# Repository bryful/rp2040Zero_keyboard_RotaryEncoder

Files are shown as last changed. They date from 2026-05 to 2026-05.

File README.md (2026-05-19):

# RP2040 Zero Macro Keyboard + Dual Rotary Encoder

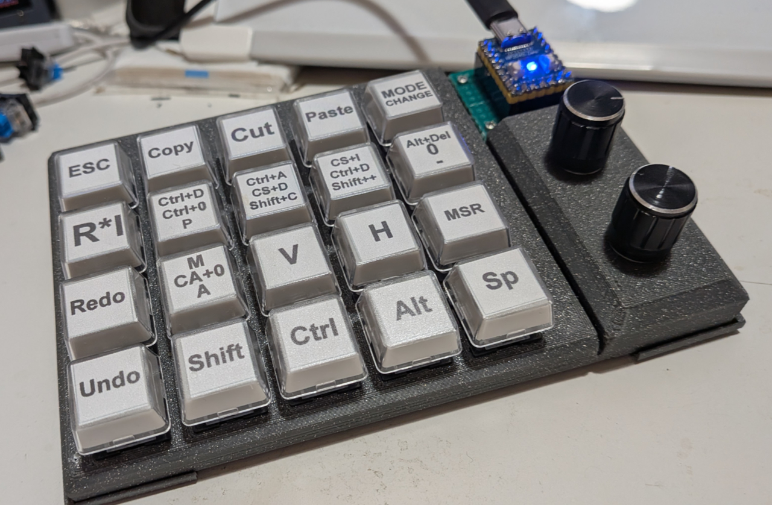
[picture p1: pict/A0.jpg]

Waveshare RP2040 Zero 用の USB HID マクロキーボードです。
4x5 キーマトリクスと 2 基のロータリーエンコーダを入力として使い、
Photoshop / After Effects / Illustrator の 3 モードでショートカットを送信します。
<br>
3dpフォルダの中に3Dプリンター用のデータも入れてあります。

## 特徴

- 4x5 キーマトリクス（20 キー）
- ロータリーエンコーダ x2（回転 CW/CCW + 押し込み SW）
- 3 つのアプリ向けキーマップモード
- モード切替キー（%1）
- USB HID キーボード + マウス右クリック送信
- WS2812 (NeoPixel) 1 灯で状態表示
- 一定時間無操作時のマウスジグル
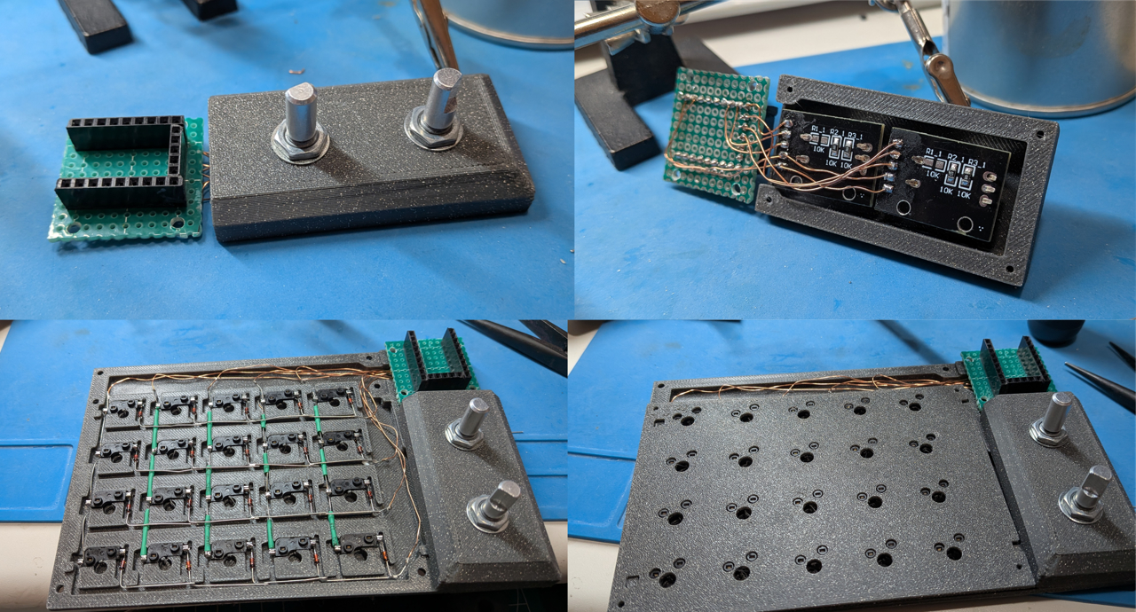
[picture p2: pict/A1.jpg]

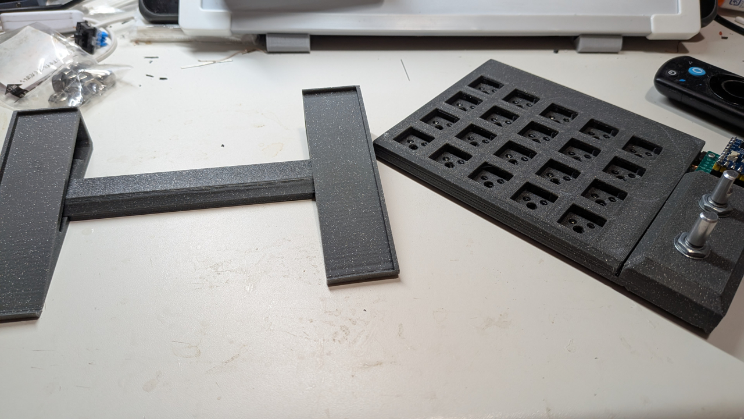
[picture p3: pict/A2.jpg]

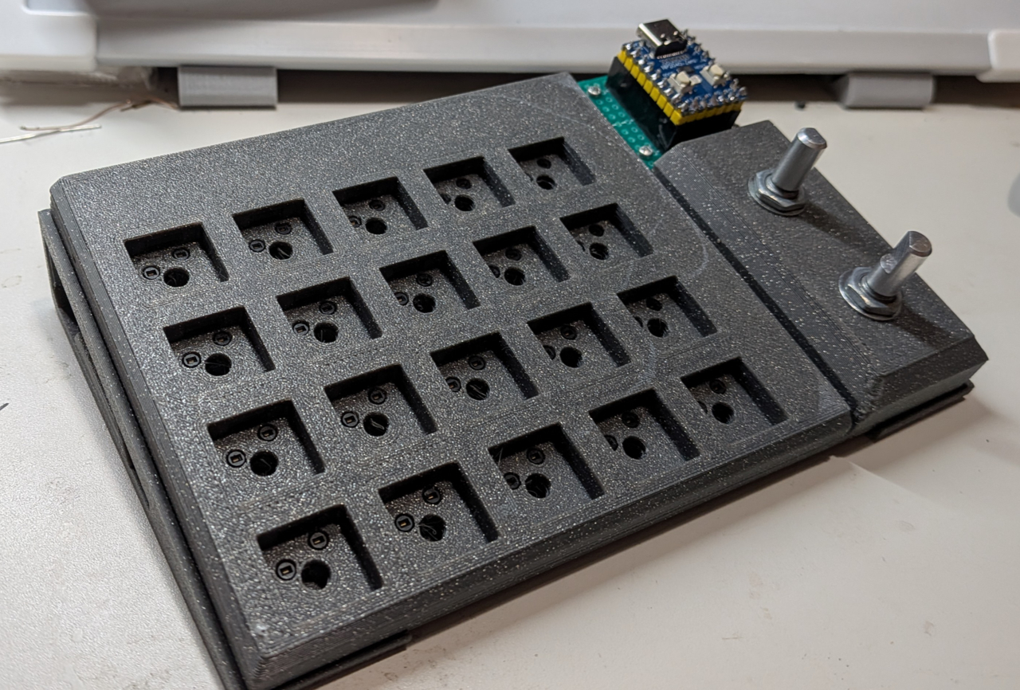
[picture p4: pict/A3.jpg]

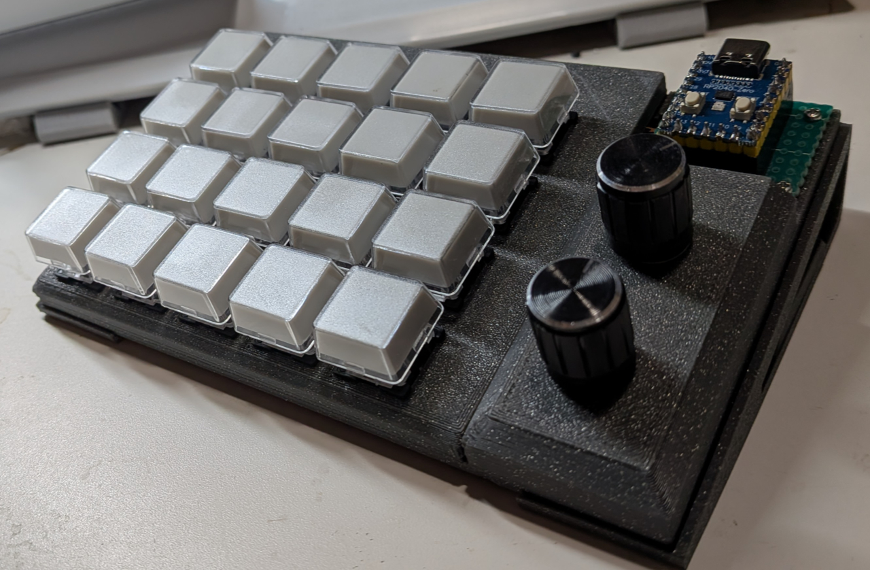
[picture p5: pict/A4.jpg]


## 日本語キーボード
ardiunoの基本だと英語キーボードになってます。そのままだと使えないので ** USBHIDKeyboard_JIS.h ** を作成し無理やり対応させています。

## ハードウェア

| 項目 | 内容 |
| --- | --- |
| マイコン | Waveshare RP2040 Zero |
| フレームワーク | Arduino (PlatformIO) |
| USB | TinyUSB ベース HID（Keyboard/Mouse） |
| LED | WS2812 x1（GPIO16） |
| キー入力 | 4x5 マトリクス（Rows: GPIO5,4,3,2 / Cols: GPIO6,7,8,9,10） |
| ロータリーエンコーダ | 2 基（A/B/SW それぞれ GPIO 割当あり） |

キー入力は INPUT_PULLUP 想定です（スイッチ押下で GND に落とす配線）。

## ピンアサイン

### キーマトリクス

| 種別 | GPIO |
| ---- | --- |
| Row  | 5, 4, 3, 2 |
| Col  | 6, 7, 8, 9, 10 |

### ロータリーエンコーダ

| エンコーダ | CLK(A) | DT(B) | SW  |
| --- | --- | ----- | --- |
| Encoder 1  | 11 | 12 | 13  |
| Encoder 2  | 14 | 15 | 26  |

### LED

| デバイス | GPIO |
| --- | ---- |
| WS2812 | 16 |

## モードとキーマップ

モードは 3 つです。

1. Photoshop
2. After Effects
3. Illustrator

モード切替キー（%1）を押すと順番に切り替わります。

### 共通キー（全モード共通）

キー割り当てはアプリを作って作成しました。
[https://github.com/bryful/rp2040Zero_Keybord](https://github.com/bryful/rp2040Zero_Keybord)

- ESC
- Ctrl+C
- Ctrl+X
- Ctrl+V
- Ctrl+Shift+Z（Redo）
- Ctrl+Z（Undo）
- Shift / Ctrl / Alt / Space
- Mouse Right Click

### ロータリーエンコーダ割り当て

#### Photoshop

- Enc0: CW = Ctrl+Keypad+, CCW = Ctrl+Keypad-, Push = Ctrl+0
- Enc1: CW = [, CCW = ], Push = B

#### After Effects

- Enc0: CW = -, CCW = ^, Push = なし
- Enc1: CW = ,, CCW = ., Push = なし

#### Illustrator

- Enc0: CW = Ctrl+Keypad+, CCW = Ctrl+Keypad-, Push = Ctrl+0
- Enc1: CW = Shift+H, CCW = V, Push = Ctrl+Shift+1

## LED 動作

- 起動時: 赤
- 起動完了時: 緑を点滅後にモード色へ遷移
- モード表示
  - Photoshop: 消灯
  - After Effects: 暗い青
  - Illustrator: 暗い黄

## スクリーンセーバー対策

一定時間入力がない場合、マウスポインタを小さく往復移動させるマウスジグルを実行します。

デフォルトは 3 分です。

```cpp
constexpr uint32_t SCREENSAVER_TIMEOUT_MS = 60000 * 3;
```

## ビルドと書き込み

### 必要環境

- VS Code
- PlatformIO 拡張
- RP2040 Zero（BOOTSEL モードで書き込み）

### PlatformIO 設定

- board: waveshare_rp2040_zero
- platform: raspberrypi
- framework: arduino
- upload_protocol: picotool
- lib_deps: Adafruit NeoPixel

### コマンド

```sh
pio run
pio run -t upload
pio device monitor -b 115200
```

## ディレクトリ構成

```text
.
|- platformio.ini
|- src/
|  |- main.cpp
|  |- USBHIDKeyboard_JIS.h
|- include/
|- lib/
|- test/
`- icons/
```

## 注意事項

- マトリクス配線はチャタリングやゴースト対策のため、必要に応じてダイオード追加を検討してください。
- 一部ショートカットは OS/アプリのキーボードレイアウト設定に依存します。
- HID キーコードの追加・調整は USBHIDKeyboard_JIS.h を編集してください。

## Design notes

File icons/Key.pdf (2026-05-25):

ESC | Copy | Cut | Paste | Mode Change

R
*
I

Ctrl+D
Ctrl+0
P

Ctrl+A
C+S+D
Shift+C

C+S+I
Ctrl+D
Shift++

Alt+Del
0

### Redo

M
C+A+0
A

A H

Mouse
R
Undo | Shift | Ctrl | Alt | Space
ESC | Copy | Cut | Paste | Mode Change

R
*
I

Ctrl+D
Ctrl+0
P

Ctrl+A
C+S+D
Shift+C

C+S+I
Ctrl+D
Shift++

Alt+Del
0

### Redo

M
C+A+0
A

A H

Mouse
R
Undo | Shift | Ctrl | Alt | Space
ESC | Copy | Cut | Paste | Mode Change

R
*
I

Ctrl+D
Ctrl+0
P

Ctrl+A
C+S+D
Shift+C

C+S+I
Ctrl+D
Shift++

Alt+Del
0

### Redo

M
C+A+0
A

A H

Mouse
R
Undo | Shift | Ctrl | Alt | Space

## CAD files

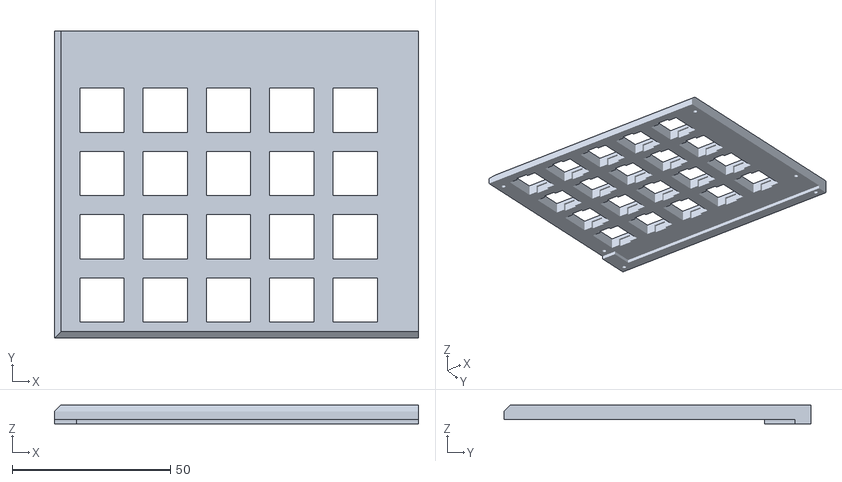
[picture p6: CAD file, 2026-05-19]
3dp/stl/Body1.stl
115.0 x 97.0 x 6.00

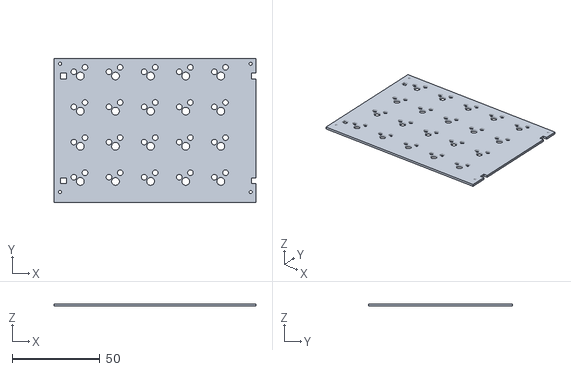
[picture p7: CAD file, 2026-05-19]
3dp/stl/Body2.stl
115.0 x 82.0 x 1.35

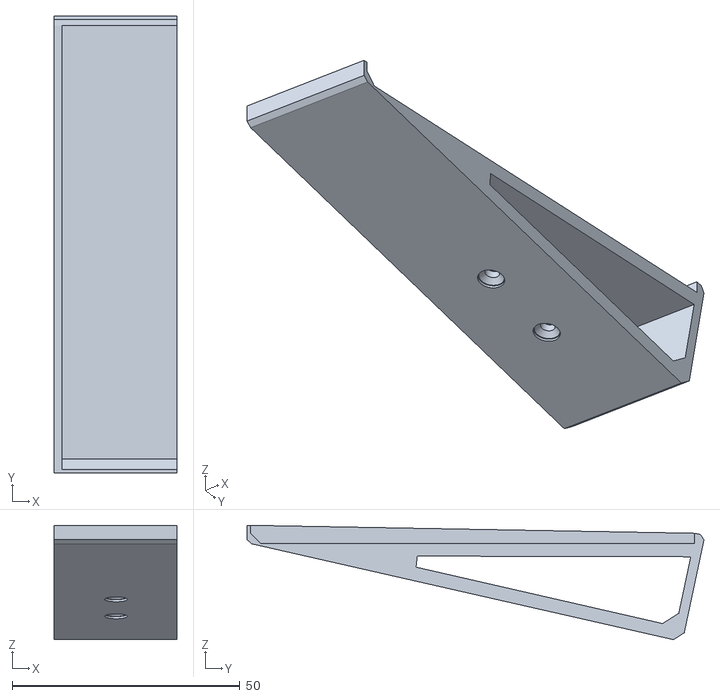
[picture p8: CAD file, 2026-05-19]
3dp/stl/A.stl
27.0 x 100.4 x 25.1

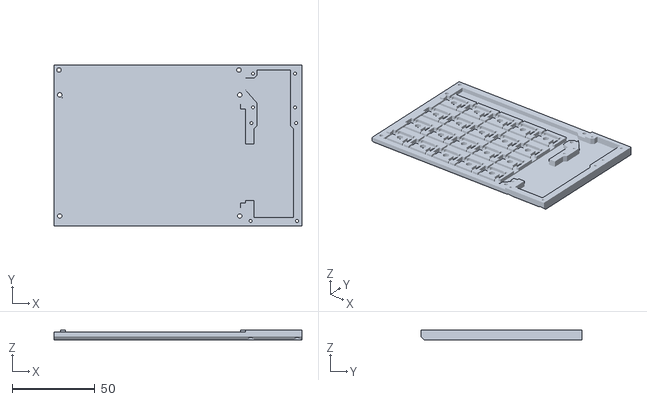
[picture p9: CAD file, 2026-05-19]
3dp/stl/Body3.stl
149.5 x 97.0 x 6.00

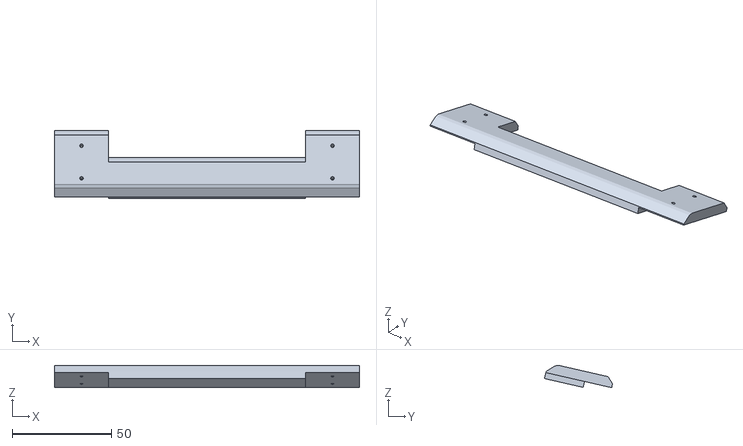
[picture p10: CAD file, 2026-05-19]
3dp/stl/C.stl
153.5 x 34.3 x 11.3

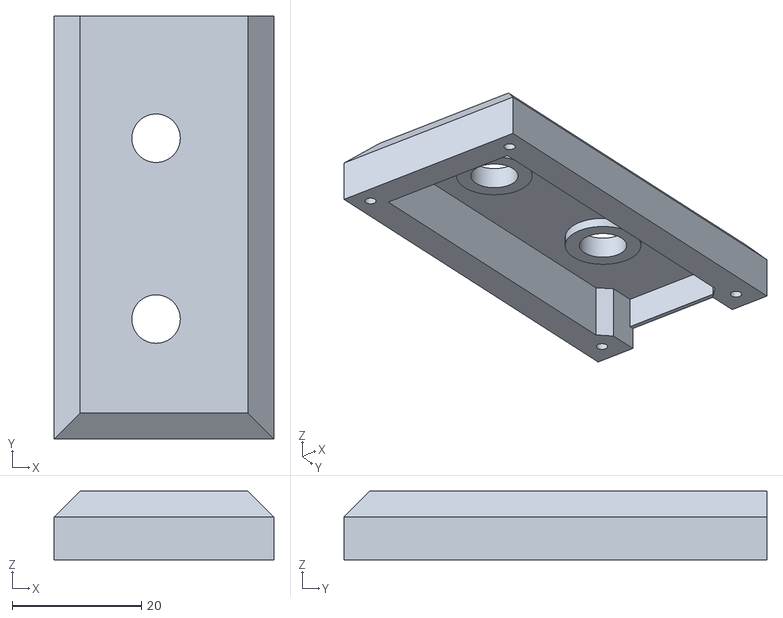
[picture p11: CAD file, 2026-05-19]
3dp/stl/Body4.stl
34.0 x 65.5 x 10.6

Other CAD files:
3dp/stl/B.stl

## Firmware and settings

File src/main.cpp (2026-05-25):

#include <Arduino.h>
#include <Keyboard.h>
#include <Mouse.h>
#include <CoreMutex.h>
#include <RP2040USB.h>
#include <tusb.h>
#include "class/hid/hid.h"
#include "class/hid/hid_device.h"
#include <Adafruit_NeoPixel.h>
#include "USBHIDKeyboard_JIS.h"
#include <LittleFS.h> // LittleFSを追加

/*
4x5 キーマトリクス (Row出力 / Col入力 反転対応版)
Rows（出力） -> GP5, GP4, GP3, GP2
Cols（入力_PULLUP） -> GP6, GP7, GP8, GP9, GP10

ロータリーエンコーダ1 (Enc0)
CLK: GP11, DT: GP12, SW: GP13

ロータリーエンコーダ2 (Enc1)
CLK: GP14, DT: GP15, SW: GP26
*/

// ============================================
// WS2812
// ============================================
#define LED_PIN 16
#define LED_COUNT 1
Adafruit_NeoPixel led(LED_COUNT, LED_PIN, NEO_GRB + NEO_KHZ800);

// ============================================
// スクリーンセーバー対策
// ============================================
constexpr uint32_t SCREENSAVER_TIMEOUT_MS = 60000 * 3; // 3分
uint32_t lastInputTime = 0;

// ============================================
// 色定義
// ============================================
uint32_t COLOR_OFF;

// ============================================
// 型定義・構造体
// ============================================
// キーマトリクスのピン配置 誤配線があったため、行と列のピン番号を入れ替え
const uint8_t rowPins[4] = {5, 4, 3, 2};
// const uint8_t rowPins[4] = {2, 3, 4, 5};
const uint8_t colPins[5] = {6, 7, 8, 9, 10};

enum ClickType
{
  NONE = 0,
  MOUSE_L = MOUSE_LEFT,
  MOUSE_R = MOUSE_RIGHT,
  MOUSE_M = MOUSE_MIDDLE
};

struct __attribute__((packed)) KeyConfig
{
  uint8_t modifier;
  uint8_t keycode;
  ClickType mouse;
};

struct RotaryEncoder
{
  uint8_t pinA;
  uint8_t pinB;
  uint8_t pinSW;
  int lastStateA;
  bool swOldState;

  int pulseQueue;
  uint32_t activeTimer;
  bool isKeyActive;
  KeyConfig activeCfg;
};

// モード切替用の特殊キー定義 (%1として使用)
#define KEY_MODE_CHANGE 0xFF
#define ENCODER_COUNT 2
#define MAX_LAYERS 8 // 最大レイヤー数を8に設定（メモリ空間に余裕あり）
#define CONFIG_FILE_PATH "/keymap.bin"

// 【新規仕様】1レイヤーの情報を内包する構造体
struct __attribute__((packed)) LayerInfo
{
  char layerName[16]; // レイヤー名（PCアプリ連動用）
  uint8_t ledR;       // モードLEDのRGB値
  uint8_t ledG;
  uint8_t ledB;
  KeyConfig matrix[4][5];               // 4x5キーマトリクス
  KeyConfig encoders[ENCODER_COUNT][3]; // エンコーダー2個の設定 [0:CW, 1:CCW, 2:SW]
};

// ============================================
// モード・キーマップ管理（動的可変対応）
// ============================================
uint8_t numActiveModes = 3; // 現在の有効レイヤー数（LittleFSから動的ロード）
uint8_t currentMode = 0;    // インデックス管理（0スタート）

// 最大数分でレイヤー配列をメモリ上に静的確保
LayerInfo layers[MAX_LAYERS];

RotaryEncoder encoders[] = {
    {11, 12, 13, LOW, true, 0, 0, false, {0, 0, NONE}},
    {14, 15, 26, LOW, true, 0, 0, false, {0, 0, NONE}}};
bool keyState[4][5] = {false};

// ============================================
// 同時押し用 一括送信レポートバッファ
// ============================================
uint8_t currentReportModifier = 0;
uint8_t currentReportKeys[6] = {0};

bool currentMouseL = false;
bool currentMouseR = false;
bool currentMouseM = false;

void addKeyToReport(uint8_t keycode)
{
  if (keycode == HID_KEY_NONE)
    return;
  for (int i = 0; i < 6; i++)
  {
    if (currentReportKeys[i] == keycode)
      return;
    if (currentReportKeys[i] == 0)
    {
      currentReportKeys[i] = keycode;
      return;
    }
  }
}

void addMouseToReport(ClickType mouseButton)
{
  if (mouseButton == MOUSE_L)
    currentMouseL = true;
  if (mouseButton == MOUSE_R)
    currentMouseR = true;
  if (mouseButton == MOUSE_M)
    currentMouseM = true;
}

// ============================================
// LED制御関数
// ============================================
void setLed(uint32_t color)
{
  led.setPixelColor(0, color);
  led.show();
}
void blinkLed(uint32_t color, int times, int delayMs)
{
  for (int i = 0; i < times; i++)
  {
    setLed(color);
    delay(delayMs);
    setLed(COLOR_OFF);
    delay(delayMs);
  }
}
// 【仕様変更】LayerInfoのRGB値からLEDを動的更新
void updateModeLED()
{
  if (currentMode < numActiveModes)
  {
    setLed(led.Color(layers[currentMode].ledR, layers[currentMode].ledG, layers[currentMode].ledB));
  }
  else
  {
    setLed(COLOR_OFF);
  }
}

// ============================================
// LittleFS 読み書き・シリアル通信処理
// ============================================
void loadConfigFromFlash()
{
  if (!LittleFS.begin())
    return;
  if (LittleFS.exists(CONFIG_FILE_PATH))
  {
    File f = LittleFS.open(CONFIG_FILE_PATH, "r");
    if (f)
    {
      f.read(&numActiveModes, 1);                // 1バイト目に有効レイヤー数
      f.read((uint8_t *)layers, sizeof(layers)); // 続いて構造体配列全体をロード
      f.close();
    }
  }
}

void handleSerialCommunication()
{
  if (Serial.available() > 0)
  {
    String cmd = Serial.readStringUntil('\n');
    cmd.trim();

    // PCからの保存要求受付
    if (cmd == "SAVE_CONFIG")
    {
      Serial.println("READY"); // 準備完了の返事

      // 有効レイヤー数(1バイト)を受信
      while (Serial.available() < 1)
      {
        tud_task();
      }
      Serial.readBytes(&numActiveModes, 1);
      if (numActiveModes > MAX_LAYERS)
        numActiveModes = MAX_LAYERS;

      // LayerInfo構造体配列の生バイナリを受信
      uint8_t *buf = (uint8_t *)layers;
      size_t totalSize = sizeof(layers);
      size_t received = 0;
      while (received < totalSize)
      {
        tud_task();
        if (Serial.available() > 0)
        {
          size_t amt = Serial.readBytes(buf + received, totalSize - received);
          received += amt;
        }
      }

      // LittleFSに即時書き込み
      File f = LittleFS.open(CONFIG_FILE_PATH, "w");
      if (f)
      {
        f.write(&numActiveModes, 1);
        f.write((uint8_t *)layers, sizeof(layers));
        f.close();
        Serial.println("SUCCESS");
        blinkLed(led.Color(0, 255, 0), 3, 200);
      }
      else
      {
        Serial.println("ERROR_FILE_OPEN");
        blinkLed(led.Color(255, 0, 0), 3, 200);
      }
      currentMode = 0; // モードを先頭にリセット
      updateModeLED();
    }
    // PCからの現在の設定吸い出し要求受付
    else if (cmd == "LOAD_CONFIG")
    {
      // 「有効レイヤー数」＋「バイナリ全体」を一括でPCへエコーバック
      Serial.write(&numActiveModes, 1);
      Serial.write((uint8_t *)layers, sizeof(layers));
      Serial.flush();
      blinkLed(led.Color(0, 0, 255), 3, 200);
      updateModeLED();
    }
  }
}

// ============================================
// HID送信コア関数
// ============================================
void sendReportFinal()
{
  CoreMutex m(&__usb_mutex);
  tud_task();
  if (!__USBHIDReady())
    return;

  tud_hid_keyboard_report(__USBGetKeyboardReportID(), currentReportModifier, currentReportKeys);

  if (currentMouseL)
    Mouse.press(MOUSE_LEFT);
  else
    Mouse.release(MOUSE_LEFT);
  if (currentMouseR)
    Mouse.press(MOUSE_RIGHT);
  else
    Mouse.release(MOUSE_RIGHT);
  if (currentMouseM)
    Mouse.press(MOUSE_MIDDLE);
  else
    Mouse.release(MOUSE_MIDDLE);

  tud_task();
}

// ============================================
// 監視ロジック
// ============================================
void updateEncoders()
{
  for (int i = 0; i < ENCODER_COUNT; i++)
  {
    auto &enc = encoders[i];

    // --- 1. 回転のエッジ検出 ---
    int currentStateA = digitalRead(enc.pinA);
    if (currentStateA != enc.lastStateA && currentStateA == LOW)
    {
      if (digitalRead(enc.pinB) != currentStateA)
      {
        enc.pulseQueue++;
      }
      else
      {
        enc.pulseQueue--;
      }
    }
    enc.lastStateA = currentStateA;

    // --- 2. パルス処理 ---
    if (enc.isKeyActive)
    {
      if (millis() - enc.activeTimer >= 20)
      {
        enc.isKeyActive = false;
      }
      else
      {
        currentReportModifier |= enc.activeCfg.modifier;
        addKeyToReport(enc.activeCfg.keycode);
        if (enc.activeCfg.mouse != NONE)
          addMouseToReport(enc.activeCfg.mouse);
      }
    }
    else
    {
      if (enc.pulseQueue != 0)
      {
        if (enc.pulseQueue > 0)
        {
          enc.activeCfg = layers[currentMode].encoders[i][0]; // CW (layers経由に変更)
          enc.pulseQueue--;
        }
        else
        {
          enc.activeCfg = layers[currentMode].encoders[i][1]; // CCW
          enc.pulseQueue++;
        }

        enc.isKeyActive = true;
        enc.activeTimer = millis();
        lastInputTime = millis();

        currentReportModifier |= enc.activeCfg.modifier;
        addKeyToReport(enc.activeCfg.keycode);
        if (enc.activeCfg.mouse != NONE)
          addMouseToReport(enc.activeCfg.mouse);
      }
    }

    // --- 3. スイッチ検出 ---
    bool swState = digitalRead(enc.pinSW);
    if (swState == LOW)
    {
      KeyConfig cfg = layers[currentMode].encoders[i][2]; // SW
      currentReportModifier |= cfg.modifier;
      addKeyToReport(cfg.keycode);
      if (cfg.mouse != NONE)
        addMouseToReport(cfg.mouse);
      lastInputTime = millis();
    }
    enc.swOldState = swState;
  }
}

void updateKeyMatrix()
{
  for (int r = 0; r < 4; r++)
  {
    pinMode(rowPins[r], OUTPUT);
    digitalWrite(rowPins[r], LOW);

    for (int c = 0; c < 5; c++)
    {
      bool isPressed = (digitalRead(colPins[c]) == LOW);

      if (isPressed)
      {
        KeyConfig cfg = layers[currentMode].matrix[r][c]; // layers経由に変更

        if (cfg.keycode == KEY_MODE_CHANGE)
        {
          if (keyState[r][c] == false)
          {
            // 動的な有効レイヤー数（numActiveModes）でループ処理
            currentMode = (currentMode + 1) % numActiveModes;
            updateModeLED();
          }
        }
        else
        {
          currentReportModifier |= cfg.modifier;
          addKeyToReport(cfg.keycode);
          if (cfg.mouse != NONE)
            addMouseToReport(cfg.mouse);
          lastInputTime = millis();
        }
      }
      keyState[r][c] = isPressed;
    }
    digitalWrite(rowPins[r], HIGH);
    pinMode(rowPins[r], INPUT_PULLUP);
  }
}

void sendMouseJiggle()
{
  Mouse.move(10, 0, 0);
  delay(10);
  Mouse.move(-10, 0, 0);
}
void handleScreensaver()
{
  if ((millis() - lastInputTime) >= SCREENSAVER_TIMEOUT_MS)
  {
    uint32_t prevColor = led.getPixelColor(0);
    setLed(led.Color(0, 0, 0));
    delay(100);
    setLed(led.Color(255, 255, 255));
    delay(100);
    setLed(led.Color(0, 0, 0));
    delay(100);
    setLed(prevColor);
    sendMouseJiggle();
    lastInputTime = millis();
  }
}

// 元のハードコーディングされていたデフォルト設定を構造体に初期展開する関数
void initDefaultKeymaps()
{
  numActiveModes = 3;
  layers[0].ledR = 0;
  layers[0].ledG = 0;
  layers[0].ledB = 0; // 黒(消灯)
  // Photoshop レイヤー設定 (Layer 0)
  strcpy(layers[0].layerName, "Photoshop");
  layers[0].matrix[0][0] = {0, HID_KEY_ESCAPE, NONE};
  layers[0].matrix[0][1] = {KEYBOARD_MODIFIER_LEFTCTRL, HID_KEY_C, NONE};
  layers[0].matrix[0][2] = {KEYBOARD_MODIFIER_LEFTCTRL, HID_KEY_X, NONE};
  layers[0].matrix[0][3] = {KEYBOARD_MODIFIER_LEFTCTRL, HID_KEY_V, NONE};
  layers[0].matrix[0][4] = {0, KEY_MODE_CHANGE, NONE};
  layers[0].matrix[1][0] = {0, HID_KEY_R, NONE};
  layers[0].matrix[1][1] = {KEYBOARD_MODIFIER_LEFTCTRL, HID_KEY_D, NONE};
  layers[0].matrix[1][2] = {KEYBOARD_MODIFIER_LEFTCTRL, HID_KEY_A, NONE};
  layers[0].matrix[1][3] = {KEYBOARD_MODIFIER_LEFTCTRL | KEYBOARD_MODIFIER_LEFTSHIFT, HID_KEY_I, NONE};
  layers[0].matrix[1][4] = {KEYBOARD_MODIFIER_LEFTALT, HID_KEY_DELETE, NONE};
  layers[0].matrix[2][0] = {KEYBOARD_MODIFIER_LEFTCTRL | KEYBOARD_MODIFIER_LEFTSHIFT, HID_KEY_Z, NONE};
  layers[0].matrix[2][1] = {0, HID_KEY_M, NONE};
  layers[0].matrix[2][2] = {0, HID_KEY_V, NONE};
  layers[0].matrix[2][3] = {0, HID_KEY_H, NONE};
  layers[0].matrix[2][4] = {0, HID_KEY_NONE, MOUSE_R};
  layers[0].matrix[3][0] = {KEYBOARD_MODIFIER_LEFTCTRL, HID_KEY_Z, NONE};
  layers[0].matrix[3][1] = {KEYBOARD_MODIFIER_LEFTSHIFT, HID_KEY_NONE, NONE};
  layers[0].matrix[3][2] = {KEYBOARD_MODIFIER_LEFTCTRL, HID_KEY_NONE, NONE};
  layers[0].matrix[3][3] = {KEYBOARD_MODIFIER_LEFTALT, HID_KEY_NONE, NONE};
  layers[0].matrix[3][4] = {0, HID_KEY_SPACE, NONE};
  layers[0].encoders[0][0] = {KEYBOARD_MODIFIER_LEFTCTRL, HID_KEY_KP_PLUS, NONE};
  layers[0].encoders[0][1] = {KEYBOARD_MODIFIER_LEFTCTRL, HID_KEY_KP_MINUS, NONE};
  layers[0].encoders[0][2] = {KEYBOARD_MODIFIER_LEFTCTRL, HID_KEY_0, NONE};
  layers[0].encoders[1][0] = {0, HID_KEY_LEFTBRACE, NONE};
  layers[0].encoders[1][1] = {0, HID_KEY_RIGHTBRACE, NONE};
  layers[0].encoders[1][2] = {0, HID_KEY_B, NONE};

  // AfterEffects レイヤー設定 (Layer 1)
  strcpy(layers[1].layerName, "AfterEffects");
  layers[1].ledR = 0;
  layers[1].ledG = 0;
  layers[1].ledB = 64; // 暗い青
  layers[1].matrix[0][0] = {0, HID_KEY_ESCAPE, NONE};
  layers[1].matrix[0][1] = {KEYBOARD_MODIFIER_LEFTCTRL, HID_KEY_C, NONE};
  layers[1].matrix[0][2] = {KEYBOARD_MODIFIER_LEFTCTRL, HID_KEY_X, NONE};
  layers[1].matrix[0][3] = {KEYBOARD_MODIFIER_LEFTCTRL, HID_KEY_V, NONE};
  layers[1].matrix[0][4] = {0, KEY_MODE_CHANGE, NONE};
  layers[1].matrix[1][0] = {0, HID_KEY_KP_ASTERISK, NONE};
  layers[1].matrix[1][1] = {KEYBOARD_MODIFIER_LEFTCTRL, HID_KEY_0, NONE};
  layers[1].matrix[1][2] = {KEYBOARD_MODIFIER_LEFTCTRL | KEYBOARD_MODIFIER_LEFTSHIFT, HID_KEY_D, NONE};
  layers[1].matrix[1][3] = {KEYBOARD_MODIFIER_LEFTCTRL, HID_KEY_D, NONE};
  layers[1].matrix[1][4] = {0, HID_KEY_0, NONE};
  layers[1].matrix[2][0] = {KEYBOARD_MODIFIER_LEFTCTRL | KEYBOARD_MODIFIER_LEFTSHIFT, HID_KEY_Z, NONE};
  layers[1].matrix[2][1] = {KEYBOARD_MODIFIER_LEFTCTRL | KEYBOARD_MODIFIER_LEFTALT, HID_KEY_0, NONE};
  layers[1].matrix[2][2] = {0, HID_KEY_V, NONE};
  layers[1].matrix[2][3] = {0, HID_KEY_H, NONE};
  layers[1].matrix[2][4] = {0, HID_KEY_NONE, MOUSE_R};
  layers[1].matrix[3][0] = {KEYBOARD_MODIFIER_LEFTCTRL, HID_KEY_Z, NONE};
  layers[1].matrix[3][1] = {KEYBOARD_MODIFIER_LEFTSHIFT, HID_KEY_NONE, NONE};
  layers[1].matrix[3][2] = {KEYBOARD_MODIFIER_LEFTCTRL, HID_KEY_NONE, NONE};
  layers[1].matrix[3][3] = {KEYBOARD_MODIFIER_LEFTALT, HID_KEY_NONE, NONE};
  layers[1].matrix[3][4] = {0, HID_KEY_SPACE, NONE};
  layers[1].encoders[0][0] = {0, HID_KEY_MINUS, NONE};
  layers[1].encoders[0][1] = {0, HID_KEY_CARET, NONE};
  layers[1].encoders[0][2] = {0, HID_KEY_NONE, NONE};
  layers[1].encoders[1][0] = {0, HID_KEY_COMMA, NONE};
  layers[1].encoders[1][1] = {0, HID_KEY_DOT, NONE};
  layers[1].encoders[1][2] = {0, HID_KEY_NONE, NONE};

  // Illustrator レイヤー設定 (Layer 2)
  strcpy(layers[2].layerName, "Illustrator");
  layers[2].ledR = 64;
  layers[2].ledG = 64;
  layers[2].ledB = 0; // 暗い黄
  layers[2].matrix[0][0] = {0, HID_KEY_ESCAPE, NONE};
  layers[2].matrix[0][1] = {KEYBOARD_MODIFIER_LEFTCTRL, HID_KEY_C, NONE};
  layers[2].matrix[0][2] = {KEYBOARD_MODIFIER_LEFTCTRL, HID_KEY_X, NONE};
  layers[2].matrix[0][3] = {KEYBOARD_MODIFIER_LEFTCTRL, HID_KEY_V, NONE};
  layers[2].matrix[0][4] = {0, KEY_MODE_CHANGE, NONE};
  layers[2].matrix[1][0] = {0, HID_KEY_I, NONE};
  layers[2].matrix[1][1] = {0, HID_KEY_P, NONE};
  layers[2].matrix[1][2] = {KEYBOARD_MODIFIER_LEFTSHIFT, HID_KEY_C, NONE};
  layers[2].matrix[1][3] = {KEYBOARD_MODIFIER_LEFTSHIFT, HID_KEY_KP_PLUS, NONE};
  layers[2].matrix[1][4] = {0, HID_KEY_MINUS, NONE};
  layers[2].matrix[2][0] = {KEYBOARD_MODIFIER_LEFTCTRL | KEYBOARD_MODIFIER_LEFTSHIFT, HID_KEY_Z, NONE};
  layers[2].matrix[2][1] = {0, HID_KEY_A, NONE};
  layers[2].matrix[2][2] = {0, HID_KEY_V, NONE};
  layers[2].matrix[2][3] = {0, HID_KEY_H, NONE};
  layers[2].matrix[2][4] = {0, HID_KEY_NONE, MOUSE_R};
  layers[2].matrix[3][0] = {KEYBOARD_MODIFIER_LEFTCTRL, HID_KEY_Z, NONE};
  layers[2].matrix[3][1] = {KEYBOARD_MODIFIER_LEFTSHIFT, HID_KEY_NONE, NONE};
  layers[2].matrix[3][2] = {KEYBOARD_MODIFIER_LEFTCTRL, HID_KEY_NONE, NONE};
  layers[2].matrix[3][3] = {KEYBOARD_MODIFIER_LEFTALT, HID_KEY_NONE, NONE};
  layers[2].matrix[3][4] = {0, HID_KEY_SPACE, NONE};
  layers[2].encoders[0][0] = {KEYBOARD_MODIFIER_LEFTCTRL, HID_KEY_KP_PLUS, NONE};
  layers[2].encoders[0][1] = {KEYBOARD_MODIFIER_LEFTCTRL, HID_KEY_KP_MINUS, NONE};
  layers[2].encoders[0][2] = {KEYBOARD_MODIFIER_LEFTCTRL, HID_KEY_0, NONE};
  layers[2].encoders[1][0] = {KEYBOARD_MODIFIER_LEFTSHIFT, HID_KEY_H, NONE};
  layers[2].encoders[1][1] = {0, HID_KEY_V, NONE};
  layers[2].encoders[1][2] = {KEYBOARD_MODIFIER_LEFTCTRL | KEYBOARD_MODIFIER_LEFTSHIFT, HID_KEY_1, NONE};
}
// ============================================
// Setup / Loop
// ============================================
void setup()
{
  led.begin();

  COLOR_OFF = led.Color(0, 0, 0);
  setLed(led.Color(255, 0, 0));

  Serial.begin(115200);

  // 初期値の代入（LittleFSにファイルが無い場合の一時退避用）
  initDefaultKeymaps();

  // LittleFSから前回保存したキーマップ設定を復元
  loadConfigFromFlash();

  for (auto &enc : encoders)
  {
    pinMode(enc.pinA, INPUT_PULLUP);
    pinMode(enc.pinB, INPUT_PULLUP);
    pinMode(enc.pinSW, INPUT_PULLUP);
  }

  for (uint8_t p : rowPins)
    pinMode(p, INPUT_PULLUP);
  for (uint8_t p : colPins)
    pinMode(p, INPUT_PULLUP);

  Keyboard.begin();
  Mouse.begin();

  for (int i = 0; i < 4; i++)
  {
    setLed(led.Color(0, 255, 0));
    delay(150);
    setLed(COLOR_OFF);
    delay(150);
  }
  updateModeLED();
  Serial.println("Keyboard Ready");
}

void loop()
{
  // 0. シリアル通信経由のPC側アプリからの読み書き要求を処理
  handleSerialCommunication();

  // 1. 毎フレームレポートバッファをリセット
  currentReportModifier = 0;
  memset(currentReportKeys, 0, sizeof(currentReportKeys));
  currentMouseL = false;
  currentMouseR = false;
  currentMouseM = false;

  // 2. 現在の物理的な「押し下げ状態」をスキャンして蓄積
  updateEncoders();
  updateKeyMatrix();

  // 3. 確定した最新レポートを一括でPCへ送信
  sendReportFinal();

  handleScreensaver();
  delay(1);
}

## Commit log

2026-05-18 feat: add shortcut configurations for Photoshop, AfterEffects, and Illustrator
    [main.cpp]
2026-05-18 feat: change default mode to Photoshop and update LED behavior for modes
2026-05-18 fix: remove unnecessary modifiers from encoder configuration
    [main.cpp]
2026-05-18 feat: refactor encoder handling and improve report sending mechanism
2026-05-19 Add new STL files and update README for RP2040 Zero Macro Keyboard
    - Added STL files for 3D printing: A.stl, B.stl, Body1.stl, Body2.stl, Body3.stl, Body4.stl, C.stl.
    - Updated README.md to reflect new features, hardware specifications, pin assignments, LED behavior, and build instructions for the RP2040 Zero Macro Keyboard with dual rotary encoders.
    - Included images for better visualization of the project.
    [A.stl, B.stl, Body1.stl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]
2026-05-19 feat: add README files for 3D printer data and keycap icons, remove main.zip
2026-05-19 docs: 日本語キーボードの説明を追加し、キー割り当てのリンクを更新
2026-05-24 feat: 構造体を使用したレイヤー管理の追加とLittleFSによる設定の読み書き機能を実装
2026-05-25 refactor: 不要な色定義を削除し、キーマトリクスのピン配置を修正。LED点滅機能を追加
2026-05-25 feat: VSCode設定ファイルを追加し、platformio.iniのビルドフラグを修正。Key.pdfのフォーマットを改善
